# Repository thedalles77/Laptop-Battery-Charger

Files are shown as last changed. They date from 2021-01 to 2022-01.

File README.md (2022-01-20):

# Laptop-Battery-Charger
This repository has all the files that I used to repurpose a Dell D630 laptop into a portable Raspberry Pi. 

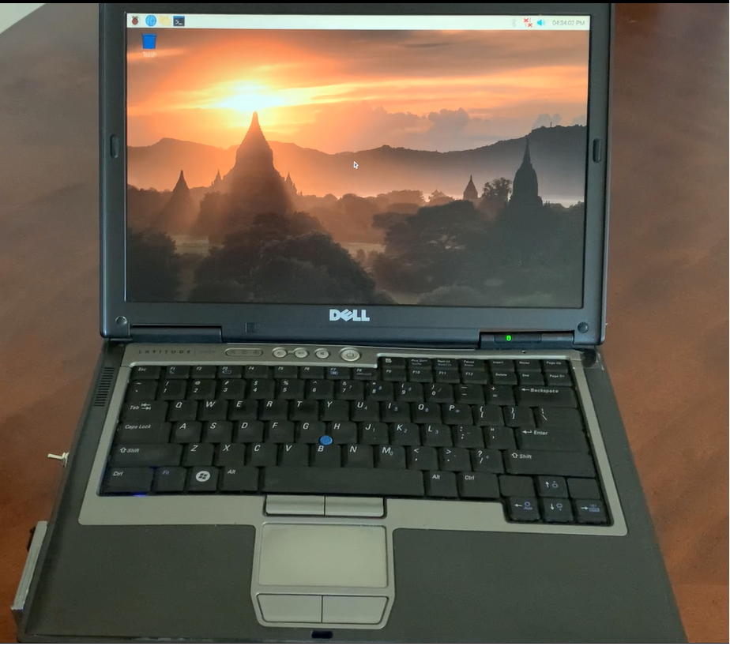
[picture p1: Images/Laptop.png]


The Instructable "Battery Powered Raspberry Pi in Repurposed Laptop" is at this url:

https://www.instructables.com/Battery-Powered-Raspberry-Pi-in-Repurposed-Laptop/

The Video "Portable Raspberry Pi Laptop with a Custom Battery Charger" is at this url:

https://vimeo.com/504006511

The Max1873 based battery charge controller board shown below is detailed as a 
Hackster.IO project at this url:

https://www.hackster.io/frank-adams/laptop-battery-charge-controller-e9c3dc

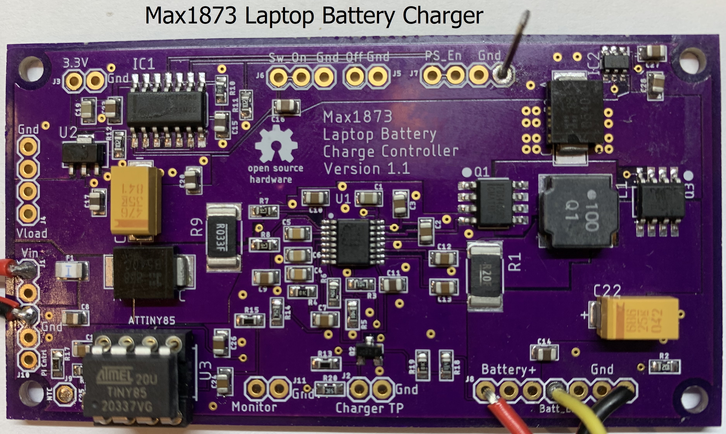
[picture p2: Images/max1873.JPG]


The MP26123 based battery charge controller board shown below is detailed as a 
Hackaday.IO project at this url:

https://hackaday.io/project/177700/details/

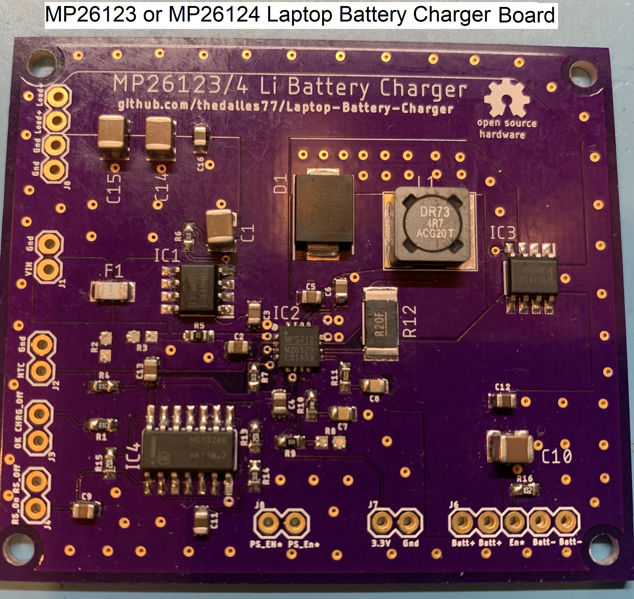
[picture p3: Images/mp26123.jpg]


A battery fuel gauge using Cairo can be found at this location: 
https://github.com/thedalles77/Raspberry-Pi-easy-drawing

The folders at this repo are organized as follows:

  AT Tiny Supervisor folder contains the AT Tiny 85 code to supervise the charging of a 3 series or 4 series wired battery pack.
  
  Eagle_Board_Files folder contains two folders: One for the Max1873 board and one for the MP26123_4 board. They contain the Eagle layout and schematic, parts list, and test procedure.
  
  Dell_D630_Portable_Pi_KVM folder contains the keyboard matrix and Teensy 3.2 Arduino code for controlling the keyboard, touchpad, and video converter card.
  
  My_Ugly_C_Code folder contains the Pi C code that reads the battery status registers over the SMBus.
  
  USB_SMBUS_CP2112 folder contains the Eagle board files to build a USB to SM Bus bridge for reading the battery status registers. See https://github.com/thedalles77/cp2112_demo for the code to display the battery status registers.
  
  Load_Switch_NCP_45760 folder contains the Eagle board files to build a load switch using the On Semiconductor NCP45760 chip.

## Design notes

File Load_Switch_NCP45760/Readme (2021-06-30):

I had problems getting this NCP45760IMN24RTWG load switch to work but I'll provide the information in case someone else has better luck. 
Let me know if you find a way to make it work.
The Eagle board and schematic files are provided along with pictures.
The 3.3 volt regulator can be an AP7381-33V-A through hole or the AP7381-33Y-13 SMD. The caps are 0805 case size and the resistors are 0603 size.
The loads on the switch were two LM2596 buck regulators that provided 10 volts to the video card and 5 volts to the Pi. 
Each buck regulator had a 100uf cap on its input and a 220uf cap on its output with more caps on the Pi and video card.
The input voltage was 19 Volts DC from a wall supply.
I started with the overcurrent resistor R2 set at 10K and the slew rate capacitor C4 set to 0.01uf but this caused the current protection circuit to trip when first enabled.
Changing the R2 resistor to a short did not change anything but changing the C4 slew rate cap to 1uf allowed the switch to work without tripping the protection circuit.
It ran for 30 minutes and the temperature on the chip and input/output traces stabilized at 52 deg C.
Unfortuantely the load switch would not turn off so I apparently ruined the chip by setting the slew rate to a very slow value.
Even changing the slew rate cap to 0.1uf will still exceed the Energy rating based on the formulas in the data sheet.
This leads me to believe that this chip is not usable for my configuration but it may work fine at lower voltages and/or lower currents.

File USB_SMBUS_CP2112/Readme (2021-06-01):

See Step 15 of my Instructable for more information regarding the CP2112:
https://www.instructables.com/Battery-Powered-Raspberry-Pi-in-Repurposed-Laptop/
See the forked version of Nick Dademo's repo for the modified code:
https://github.com/thedalles77/cp2112_demo

The Eagle brd file includes the recommended footprint for the slotted holes on the USB connector.
To fabricate this board at OSH Park, upload the zip file which has been run thru a CAM processor to create the proper slotted holes.

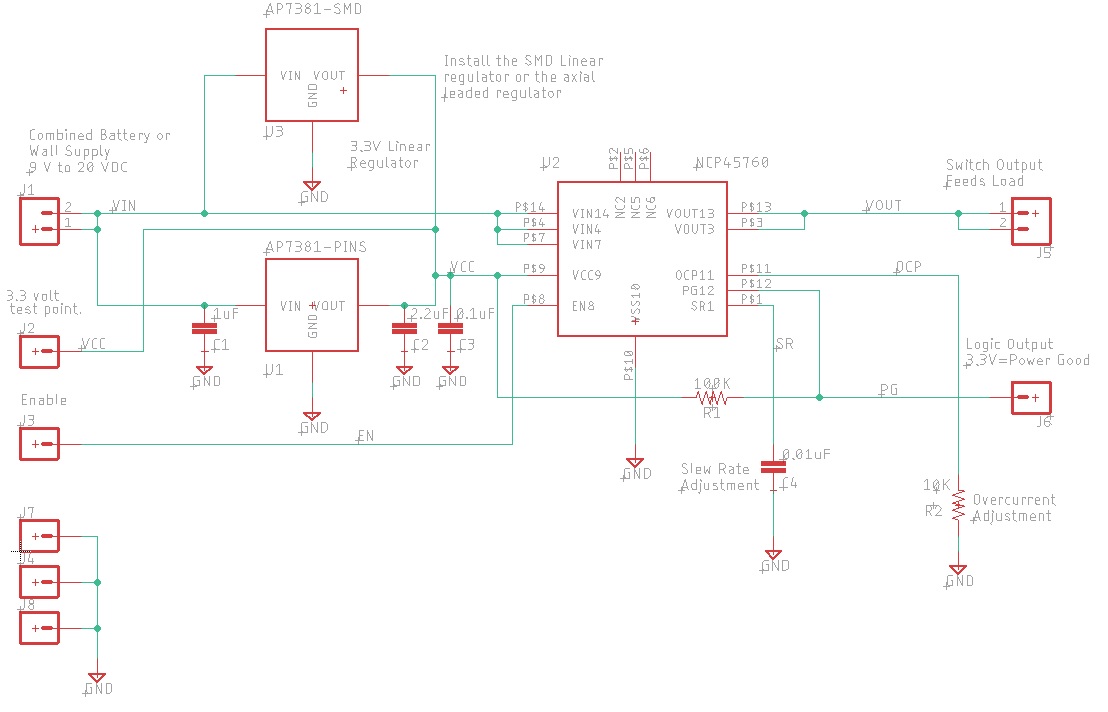
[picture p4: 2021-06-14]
Load_Switch_NCP45760/load_switch_schematic_NCP45760.jpg

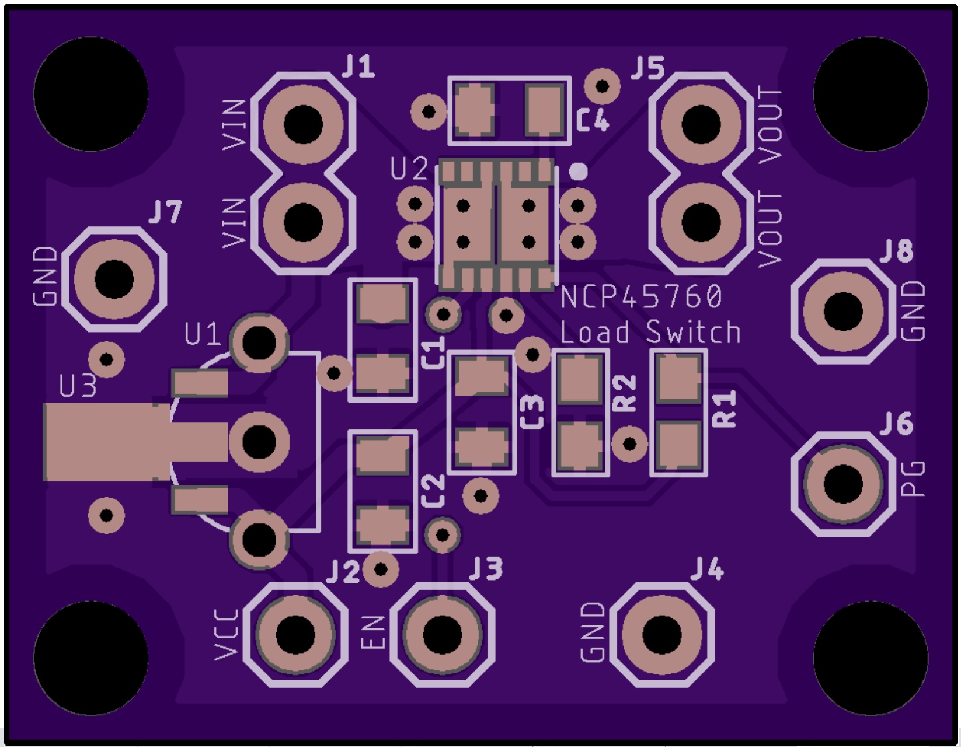
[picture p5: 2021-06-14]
Load_Switch_NCP45760/load_switch_layout_NCP45760.jpg

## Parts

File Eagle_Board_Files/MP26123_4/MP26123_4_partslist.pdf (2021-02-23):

### MP26123 (2S/3S) or MP26124 (4S) Battery Charger Board Parts List

Qty | Description | P/N | Digikey # | Price | Package
1 | Charge Controller 2S/3S MP26123DR-LF-Z 1589-1609-1-ND (https://www.digikey.com/en/products/detail/monolithic-power-systems-inc/MP26123DR-LF-Z/5292163) | $4.92 16-VQFN
Charge Controller 4S | MP26124GR-Z | 1589-1993-1-ND (https://www.digikey.com/en/products/detail/monolithic-power-systems-inc/MP26124GR-Z/8342003) | $4.92 | 16-VQFN
1 | 4.7uH Inductor (2S/3S) | DR73-4R7-R | 513-1133-1-ND (https://www.digikey.com/en/products/detail/eaton-electronics-division/DR73-4R7-R/667201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) | $0.92 | SMD
10uH Inductor (4S) NRS8030T100MJGJ | 587-2960-1-ND (https://www.digikey.com/product-detail/en/taiyo-yuden/NRS8030T100MJGJ/587-2960-1-ND/2666065) | $0.45 | SMD
1 | 3.3 volt regulator | AP7381-33Y-13 | AP7381-33Y-13DICT-ND (https://www.digikey.com/en/products/detail/AP7381-33Y-13/AP7381-33Y-13DIDKR-ND/7914858?itemSeq=322354340) | $0.44 | SOT89
1 | Quad NAND gate | MC74HC132ADTG | MC74HC132ADGOS-ND (https://www.digikey.com/product-detail/en/on-semiconductor/MC74HC132ADG/MC74HC132ADGOS-ND/1479854) $0.37 | 14 pin SOIC
2 | P-FET | FDS4435BZ | FDS4435BZCT-ND (https://www.digikey.com/product-detail/en/on-semiconductor/FDS4435BZ/FDS4435BZCT-ND/1305829) | $0.60 | 8 Pin SOIC
1 | Schottky Diode | B540C | B540C-FDICT-ND (https://www.digikey.com/en/products/detail/diodes-incorporated/B540C-13-F/768771) | $0.48 | DO-214AB
1 | Fuse 5A 32V Slow blow 0469005.WR | F3539CT-ND (https://www.digikey.com/product-detail/en/littelfuse-inc/0469005.WR/F3539CT-ND/2297397) | $0.81 | 1206
5 | 0.1uf 50V X5R Cap | UMK212BJ104KG-T | 587-5486-1-ND (https://www.digikey.com/product-detail/en/taiyo-yuden/UMK212BJ104KG-T/587-5486-1-ND/7067162) | $0.08 | 0805
1 | 0.15uf 50V X5R Cap C2012X7R1H154K085AA 445-14541-1-ND (https://www.digikey.com/en/products/detail/tdk-corporation/C2012X7R1H154K085AA/3951777) | $0.19 | 0805
4 | 1uf 35V Cap | GMK212B7105KG-T | 587-1438-1-ND (https://www.digikey.com/product-detail/en/taiyo-yuden/GMK212B7105KG-T/587-1438-1-ND/1004069) | $0.25 | 0805
1 | 2.2uf 35V Cap | CGA4J1X7R1V225M125AC 445-12769-1-ND (https://www.digikey.com/en/products/detail/tdk-corporation/CGA4J1X7R1V225M125AC/3950005) | $0.51 | 0805
1 | 4.7uf Cap | C1210C475K5RACTU | 399-6785-1-ND (https://www.digikey.com/en/products/detail/kemet/C1210C475K5RACTU/2216923) | $0.60 | 1210
2 | 10uf Cap | GMK325AB7106MM-T | 587-2779-1-ND (https://www.digikey.com/en/products/detail/taiyo-yuden/GMK325AB7106MM-T/2573866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) | $0.69 | 1210
1 | 22uf Cap | C1210C226K3PACTU | 399-11404-1-ND (https://www.digikey.com/en/products/detail/kemet/C1210C226K3PACTU/4747726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) | $0.72 | 1210
2 | 2200pf Cap (2S/3S) CL21B222JBANNNC | 1276-2478-1-ND (https://www.digikey.com/en/products/detail/samsung-electro-mechanics/CL21B222JBANNNC/3888136) | $0.10 | 0805
1 | 2200pf Cap (4S) CL21B222JBANNNC | 1276-2478-1-ND (https://www.digikey.com/en/products/detail/samsung-electro-mechanics/CL21B222JBANNNC/3888136) | $0.10 | 0805

1 4700pf Cap (4S) C0805C472K5RAC7025 C0805C472K5RAC7025CT-ND (https://www.digikey.com/en/products/detail/kemet/C0805C472K5RAC7025/12701326) $0.11 0805

6 | 10KΩ 1% | RNCP0603FTD10K | RNCP0603FTD10K0CT-ND (https://www.digikey.com/product-detail/en/stackpole-electronics-inc/RNCP0603FTD10K0/RNCP0603FTD10K0CT-ND/2240478) | $0.10 | 0603
1 | 10Ω 0.3W | SDR03EZPF10R0 | 511-1693-1-ND (https://www.digikey.com/en/products/detail/rohm-semiconductor/SDR03EZPF10R0/9674943) $0.13 | 0603
3 | 1KΩ 5% | RC0603JR-071KL | 311-1.0KGRCT-ND (https://www.digikey.com/product-detail/en/yageo/RC0603JR-071KL/311-1.0KGRCT-ND/729624) | $0.10 | 0603
1 | 2.49KΩ | RNCP0603FTD2K49 RNCP0603FTD2K49CT-ND (https://www.digikey.com/en/products/detail/stackpole-electronics-inc/RNCP0603FTD2K49/2240117) | $0.10 | 0603
1 | 750Ω | CRCW0603750RFKEAC 541-5551-1-ND (https://www.digikey.com/en/products/detail/vishay-dale/CRCW0603750RFKEAC/7924016) | $0.10 | 0603
1 | 0.2Ω 1% 1W | WSL2512R2000FEA WSLG-.20CT-ND (https://www.digikey.com/product-detail/en/vishay-dale/WSL2512R2000FEA/WSLG-20CT-ND/713508) | $1.05 | 2512

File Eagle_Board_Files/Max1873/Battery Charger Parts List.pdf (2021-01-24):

# Parts List - Laptop Battery Charge Controller

Qty | Description | P/N | Digikey # | Price | Package
1 | Charge Controller 2s MAX1873REEE+ | MAX1873REEE+-ND (https://www.digikey.com/product-detail/en/maxim-integrated/MAX1873REEE/MAX1873REEE-ND/1513342) | $4.26 | 16 Pin QSOP
Charge Controller 3s MAX1873SEEE+ | MAX1873SEEE+-ND (https://www.digikey.com/product-detail/en/MAX1873SEEE%2b/MAX1873SEEE%2b-ND/1513376/?itemSeq=316588766) | $3.78 | 16 Pin QSOP
Charge Controller 4s MAX1873TEEE+ | MAX1873TEEE+-ND (https://www.digikey.com/product-detail/en/maxim-integrated/MAX1873TEEE/MAX1873TEEE-ND/1513377) | $3.78 | 16 Pin QSOP
1 | 3.3 volt regulator | AP7381-33Y-13 | AP7381-33Y-13DICT-ND (https://www.digikey.com/en/products/detail/AP7381-33Y-13/AP7381-33Y-13DIDKR-ND/7914858?itemSeq=322354340) | $0.44 | SOT89
1 | Quad NAND gate | MC74HC132ADTG | MC74HC132ADGOS-ND (https://www.digikey.com/product-detail/en/on-semiconductor/MC74HC132ADG/MC74HC132ADGOS-ND/1479854) $0.37 | 14 pin SOIC
1 | ATTiny85 | ATTINY85-20PU | ATTINY85-20PU-ND (https://www.digikey.com/product-detail/en/microchip-technology/ATTINY85-20PU/ATTINY85-20PU-ND/735469) | $1.20 | 8 Pin DIP
2 | P-FET | FDS4435BZ | FDS4435BZCT-ND (https://www.digikey.com/product-detail/en/on-semiconductor/FDS4435BZ/FDS4435BZCT-ND/1305829) | $0.60 | 8 Pin SOIC
1 | N-FET | MMBF170 | MMBF170CT-ND (https://www.digikey.com/products/en?keywords=mmbf170ct-nd) | $0.37 | SOT-23-3
2 | Schottky Diode | B540C | B540C-FDICT-ND (https://www.digikey.com/en/products/detail/diodes-incorporated/B540C-13-F/768771) | $0.48 | DO-214AB
1 | Ideal Diode Controller LTC4412 LTC4412ES6#TRMPBFCT-ND (https://www.digikey.com/en/products/detail/analog-devices-inc/LTC4412ES6-TRMPBF/1116052) $3.44 | SOT-23-6
1 | Fuse 5A 32V Slow blow 0469005.WR | F3539CT-ND (https://www.digikey.com/product-detail/en/littelfuse-inc/0469005.WR/F3539CT-ND/2297397) | $0.81 | 1206
1 | 10uH, 3A Inductor NRS8030T100MJGJ 587-2960-1-ND (https://www.digikey.com/product-detail/en/taiyo-yuden/NRS8030T100MJGJ/587-2960-1-ND/2666065) | $0.45 | SMD
1 | 68uf, 25V Cap | T495X686K025ATE200 | 399-3908-1-ND (https://www.digikey.com/product-detail/en/T495X686K025ATE200/399-3908-1-ND/819233/?itemSeq=316593616) | $1.96 | 2917
1 | 47uf, 35V Cap | T495X476K035ATE200 399-8543-1-ND (https://www.digikey.com/product-detail/en/T495X476K035ATE200/399-8543-1-ND/3472266/?itemSeq=316593298) | $2.43 | 2917
2 | 2.2uf 10V X5R Cap CC0805MRX5R6BB225 | 311-3438-1-ND (https://www.digikey.com/product-detail/en/yageo/CC0805MRX5R6BB225/311-3438-1-ND/7164459) | $0.18 | 0805
13 | 0.1uf 50V X5R Cap | UMK212BJ104KG-T | 587-5486-1-ND (https://www.digikey.com/product-detail/en/taiyo-yuden/UMK212BJ104KG-T/587-5486-1-ND/7067162) | $0.08 | 0805
2 | 0.22uf 35V Cap | GMK212BJ224KGHT | 587-3366-1-ND (https://www.digikey.com/product-detail/en/taiyo-yuden/GMK212BJ224KGHT/587-3366-1-ND/4157374) | $0.20 | 0805
2 | 0.047uf 50V Cap | 08055C473KAT2A | 478-1391-1-ND (https://www.digikey.com/product-detail/en/avx-corporation/08055C473KAT2A/478-1391-1-ND/564423) | $0.19 | 0805
1 | 1000pf 50V Cap CC0805KRX7R9BB102 | 399-1147-1-ND (https://www.digikey.com/product-detail/en/C0805C102K5RACTU/399-1147-1-ND/411422/?itemSeq=316589801) | $0.14 | 0805
6 | 1uf 35V Cap | GMK212B7105KG-T | 587-1438-1-ND (https://www.digikey.com/product-detail/en/taiyo-yuden/GMK212B7105KG-T/587-1438-1-ND/1004069) | $0.25 | 0805
3 | 100KΩ 0.1% | ERA-3AEB104V | P100KDBCT-ND (https://www.digikey.com/product-detail/en/panasonic-electronic-components/ERA-3AEB104V/P100KDBCT-ND/1466100) | $0.35 | 0603
3 | 10KΩ 1% | RNCP0603FTD10K | RNCP0603FTD10K0CT-ND (https://www.digikey.com/product-detail/en/stackpole-electronics-inc/RNCP0603FTD10K0/RNCP0603FTD10K0CT-ND/2240478) | $0.10 | 0603
3 | 1KΩ 5% | RC0603JR-071KL | 311-1.0KGRCT-ND (https://www.digikey.com/product-detail/en/yageo/RC0603JR-071KL/311-1.0KGRCT-ND/729624) | $0.10 | 0603
2 | 4.7Ω 1% | RNCP0603FTD4R70 RNCP0603FTD4R70CT-ND (https://www.digikey.com/product-detail/en/stackpole-electronics-inc/RNCP0603FTD4R70/RNCP0603FTD4R70CT-ND/2240412) | $0.10 | 0603
1 | 2.49KΩ 0.1% | ERA-3AEB2491V | P2.49KDBCT-ND (https://www.digikey.com/product-detail/en/panasonic-electronic-components/ERA-3AEB2491V/P2.49KDBCT-ND/3075884) | $0.34 | 0603
1 | 7.5KΩ 0.1% | ERA-3AEB752V | P7.5KDBCT-ND (https://www.digikey.com/product-detail/en/panasonic-electronic-components/ERA-3AEB752V/P7.5KDBCT-ND/1466073) | $0.35 | 0603
2 | 49.9KΩ 0.1% | ERA-3AEB4992V | P49.9KDBCT-ND (https://www.digikey.com/product-detail/en/panasonic-electronic-components/ERA-3AEB4992V/P49-9KDBCT-ND/3075986) | $0.34 | 0603
1 | 82KΩ 1% | RC0603FR-0782KL | 311-82.0KHRCT-ND (https://www.digikey.com/en/products/detail/yageo/RC0603FR-0782KL/727400) | $0.10 | 0603
1 | 160KΩ 1% | RC0603FR-07160KL 311-160KHRCT-ND (https://www.digikey.com/en/products/detail/yageo/RC0603FR-07160KL/726973) | $0.10 | 0603
1 | 34.8KΩ 0.5% | RT0603DRE0734K8L 311-2545-1-ND (https://www.digikey.com/en/products/detail/yageo/RT0603DRE0734K8L/1074808) | $0.10 | 0603

1 | 0.033Ω 1% 1W | WSL2512R0330FEA | WSLG-.033CT-ND (https://www.digikey.com/product-detail/en/vishay-dale/WSL2512R0330FEA/WSLG-.033CT-ND/713498) | $1.19 | 2512
1 | 0.2Ω 1% 1W | WSL2512R2000FEA WSLG-.20CT-ND (https://www.digikey.com/product-detail/en/vishay-dale/WSL2512R2000FEA/WSLG-20CT-ND/713508) | $1.05 | 2512
1 | 8 pin Dip socket 110-43-308-41-001000 | ED90032-ND (https://www.digikey.com/product-detail/en/mill-max-manufacturing-corp/110-43-308-41-001000/ED90032-ND/947040) | $0.79 | 8 Pin DIP

### Notes:

Choose the Max1873 R, S, or T version depending on the number of series cells in your battery pack.

Resistors R5 and R6 are each 100KΩ for battery packs that use 3.7 volt nominal/4.2 volt maximum cells. These values must be changed for older battery packs that use 3.6 volt nominal/4.1 volt maximum cells. Using the formulas in the Max1873 data sheet gives new values of: R5 = 54.9KΩ (https://www.digikey.com/en/products/detail/ERA-3AEB5492V/P54.9KDBCT-ND/3076002) and R6 = 147KΩ. (https://www.digikey.com/en/products/detail/ERA-3AEB1473V/P147KDBCT-ND/3075806)

Use the Charge_Controller Eagle layout file to order the PCB from OSH Park. (https://oshpark.com/) The cost with U.S. shipping is $27 for a lot of 3 boards. Use the Charge_Controller Gerber zip file to order the PCB from JLCPCB. The cost with economy U.S. shipping is under $10 for a lot of 5 boards.

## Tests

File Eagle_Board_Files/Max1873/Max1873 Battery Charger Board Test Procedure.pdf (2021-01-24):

Max1873 Battery Charger Board Test Procedure

1. The AT Tiny 85 is not needed during the initial testing and should not be installed.
2. Perform a thorough visual check with a magnifying glass or microscope.
3. Use your ohm meter to verify there are no shorts to ground on any power node.
4. Check that the Max1873 adjacent pins are not shorted together.
5. With the battery disconnected, apply 19 volts DC to the board, preferably with a bench supply so you can dial the current limit down. Verify all voltage nodes with a meter. This should include:
- Vin 19V input
- Battery+ charge voltage. This is dependent on which Max1873 part number is installed (R, S, or T) and resistor values for R5 and R6 (3.6V vs 3.7V cells).
- Vload voltage (confirm the ideal diode circuit is working)
- AT Tiny pin 8 (5.4 Volt regulator from Max1873)
- | The 3.3V pin from the linear regulator powering the | 74HC132A.
6. Verify the digital latch circuit is working. On power up the Ps_En pin should be a logic high (3.3 volts). Momentarily touch the Sw_On pin to ground and verify the Ps_En pin is now a logic low. Momentarily touch the Off pin to 3.3 volts and verify the Ps_En pin is a logic high.
7. Disconnect the 19 volt DC source. Attach the battery to the charger board using a connector. This should tie the "system present" pin of the battery low with a 1K resistor and connect the positive and negative pins of the battery to the charger board. The battery voltage should be present at the Battery+ pin. If not, the battery may be bad or it may need a turn-on activation code over the SMBus. Use the “read_battery_loop.c” code described in the Instructable to see if the battery voltage can now be measured at the Battery+ pin and can be read over the SMBus.
8. Verify the battery voltage is present at the Vload pin – this checks that the "ideal diode" is working.
9. With the battery still connected, connect the 19 volt DC source and measure the battery voltage. Make sure it does not exceed the voltage rating for the battery. Measure the charge current at the Monitor test point. It should be about 1 volt when charging at 1 amp. If the battery voltage is correct but the charging current is near zero, use the “read_battery_loop.c” code described in the Instructable to enable charging. Monitor the battery temperature at all times while charging either by feel or with a temperature probe.
10. Once the battery charger is working properly, disconnect the 19V input and install a programmed AT Tiny 85. Connect 19 volts to the input and confirm normal battery charging operation. You may need to adjust the code in the Tiny for the following:
| • Stop charging when at 100% SOC.
- Stop charging if the temperature rise is too high.
| • Stop charging if the total time is too long.
- Stop charging if the Pi_Control input pin is at 3.3 volts.

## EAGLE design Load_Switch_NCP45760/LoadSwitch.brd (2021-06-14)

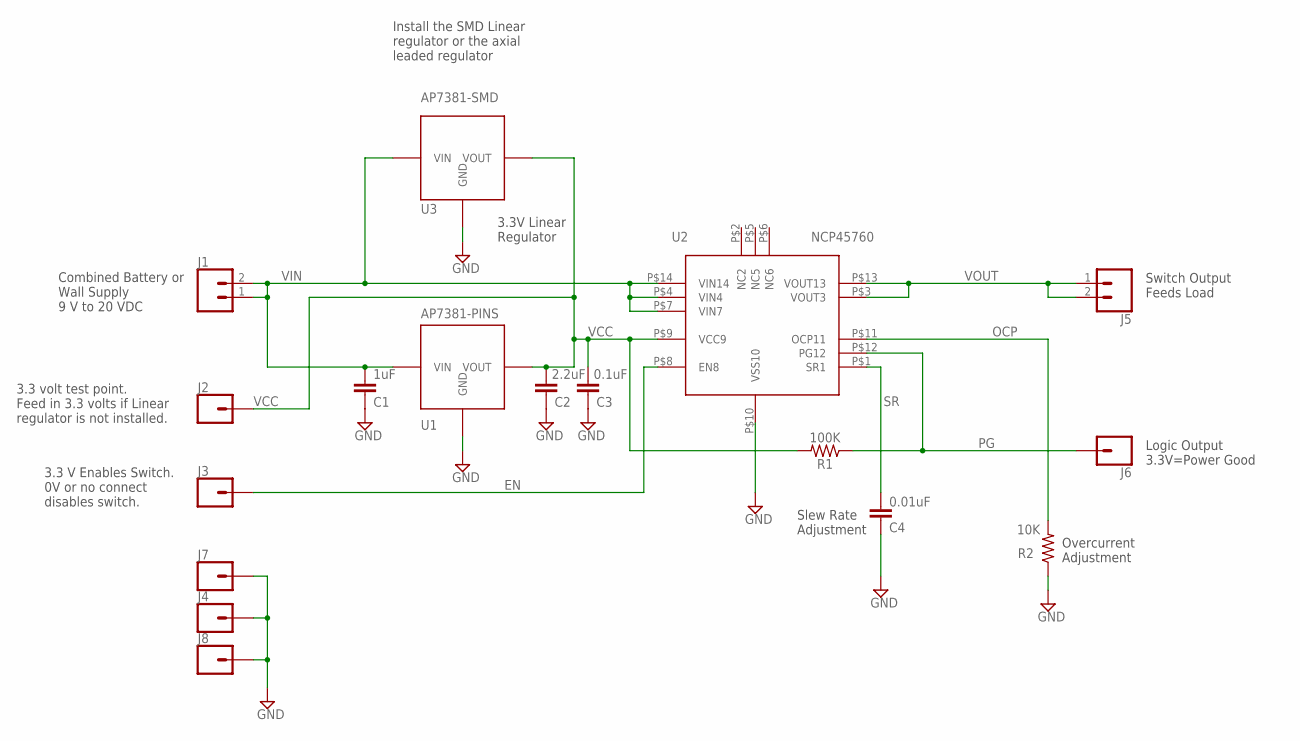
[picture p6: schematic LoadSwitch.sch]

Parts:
C1: 1uF; 0805_CAP
C2: 2.2uF; 0805_CAP
C3: 0.1uF; 0805_CAP
C4: 0.01uF; 0805_CAP
J1, J5: CONN_02; 1X02
J2, J3, J4, J6, J7, J8: CONN_01; 1X01
R1: 100K; 0603_RESISTOR
R2: 10K; 0603_RESISTOR
U1: AP7381-PINS; AP7381_PINS
U2: NCP45760
U3: AP7381-SMD; AP7381

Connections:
EN: J3.1, U2.P$8 (EN8)
GND: C1.2, C2.2, C3.2, C4.2, J4.1, J7.1, J8.1, R2.1, U1.P$2 (GND), U2.P$10 (VSS10), U3.P$3 (GND), U3.P$4 (GND)
OCP: R2.2, U2.P$11 (OCP11)
PG: J6.1, R1.1, U2.P$12 (PG12)
SR: C4.1, U2.P$1 (SR1)
VCC: C2.1, C3.1, J2.1, R1.2, U1.P$1 (VOUT), U2.P$9 (VCC9), U3.P$1 (VOUT)
VIN: C1.1, J1.1, J1.2, U1.P$3 (VIN), U2.P$4 (VIN4), U2.P$7 (VIN7), U2.P$14 (VIN14), U3.P$2 (VIN)
VOUT: J5.1, J5.2, U2.P$3 (VOUT3), U2.P$13 (VOUT13)

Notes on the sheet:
3.3V Linear Regulator
Combined Battery or Wall Supply 9 V to 20 VDC
3.3 volt test point. Feed in 3.3 volts if Linear regulator is not installed.
3.3 V Enables Switch. 0V or no connect disables switch.
Slew Rate Adjustment
Overcurrent Adjustment
Switch Output Feeds Load
Logic Output 3.3V=Power Good
Install the SMD Linear regulator or the axial leaded regulator

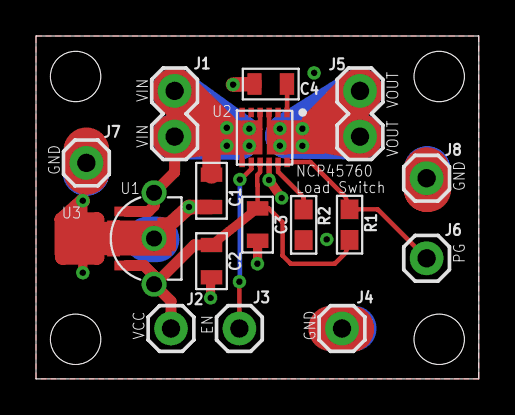
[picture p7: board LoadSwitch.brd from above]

Board: 2 copper layers, 24.6 x 19.1 mm, 18 parts (1 on the bottom side), 8 nets.

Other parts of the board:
U$1: OSHW_5MM

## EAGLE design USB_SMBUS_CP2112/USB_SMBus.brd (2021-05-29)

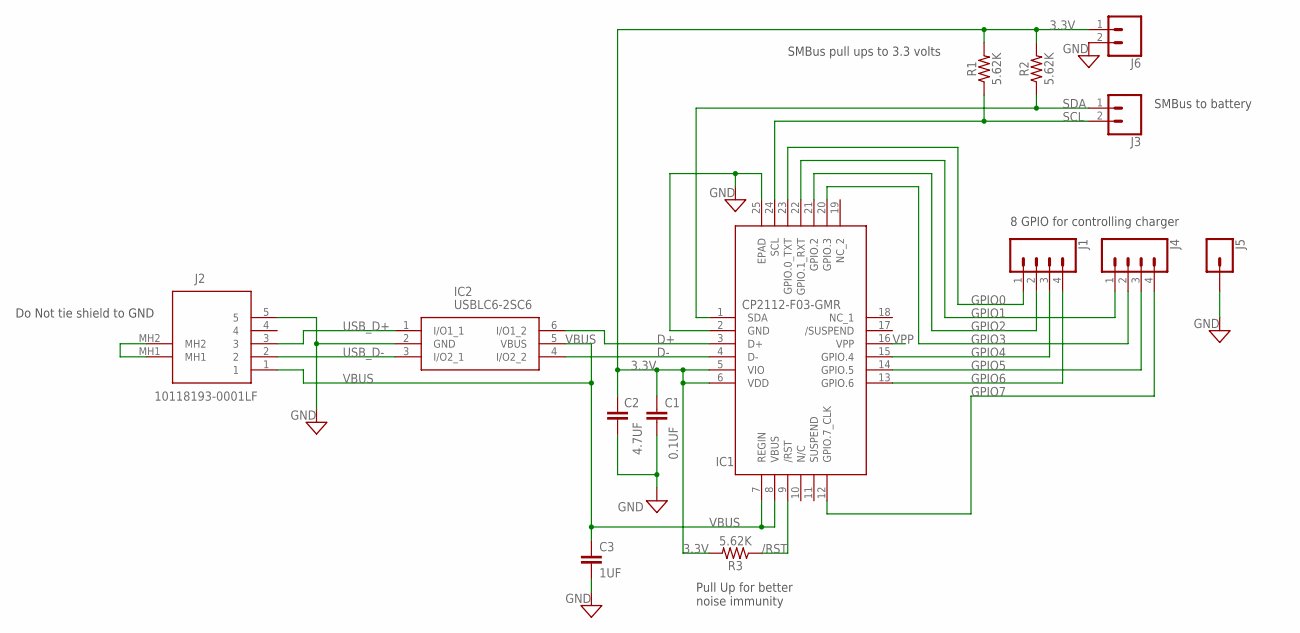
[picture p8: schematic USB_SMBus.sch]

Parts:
C1: 0.1UF; 0805_CAP
C2: 4.7UF; 0805_CAP
C3: 1UF; 0805_CAP
IC1: CP2112-F03-GMR; QFN50P400X400X80-25N
IC2: USBLC6-2SC6; SOT95P280X145-6N
J1, J4: CONN_04; 1X04
J2: 10118193-0001LF; 101181930001LF
J3, J6: CONN_02; 1X02
J5: CONN_01; 1X01
R1, R2, R3: 5.62K; 0603_RESISTOR

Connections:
3.3V: C1.1, C2.1, IC1.5 (VIO), IC1.6 (VDD), J6.1, R1.2, R2.2, R3.2
/RST: IC1.9 (/RST), R3.1
D+: IC1.3 (D+), IC2.6 (I/O1_2)
D-: IC1.4 (D-), IC2.4 (I/O2_2)
GND: C1.2, C2.2, C3.2, IC1.2 (GND), IC1.25 (EPAD), IC2.2 (GND), J2.5, J5.1, J6.2
GPIO0: IC1.23 (GPIO.0_TXT), J1.1
GPIO1: IC1.22 (GPIO.1_RXT), J4.1
GPIO2: IC1.21 (GPIO.2), J1.2
GPIO3: IC1.20 (GPIO.3), J4.2
GPIO4: IC1.15 (GPIO.4), J1.3
GPIO5: IC1.14 (GPIO.5), J4.3
GPIO6: IC1.13 (GPIO.6), J1.4
GPIO7: IC1.12 (GPIO.7_CLK), J4.4
unnamed: J2.MH1, J2.MH2
SCL: IC1.24 (SCL), J3.2, R1.1
SDA: IC1.1 (SDA), J3.1, R2.1
USB_D+: IC2.1 (I/O1_1), J2.3
USB_D-: IC2.3 (I/O2_1), J2.2
VBUS: C3.1, IC1.7 (REGIN), IC1.8 (VBUS), IC2.5 (VBUS), J2.1
VPP: IC1.16 (VPP)

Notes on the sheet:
Pull Up for better noise immunity
Do Not tie shield to GND
SMBus to battery
8 GPIO for controlling charger
SMBus pull ups to 3.3 volts

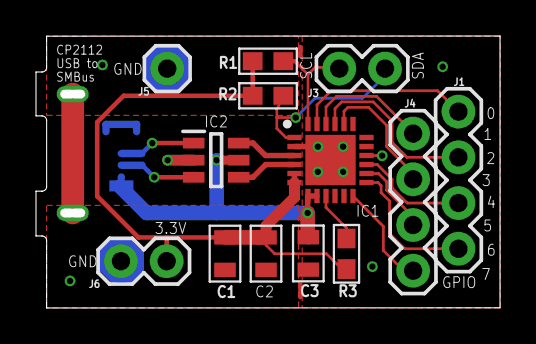
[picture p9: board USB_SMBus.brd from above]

Board: 2 copper layers, 25.8 x 15.1 mm, 14 parts (1 on the bottom side), 19 nets.

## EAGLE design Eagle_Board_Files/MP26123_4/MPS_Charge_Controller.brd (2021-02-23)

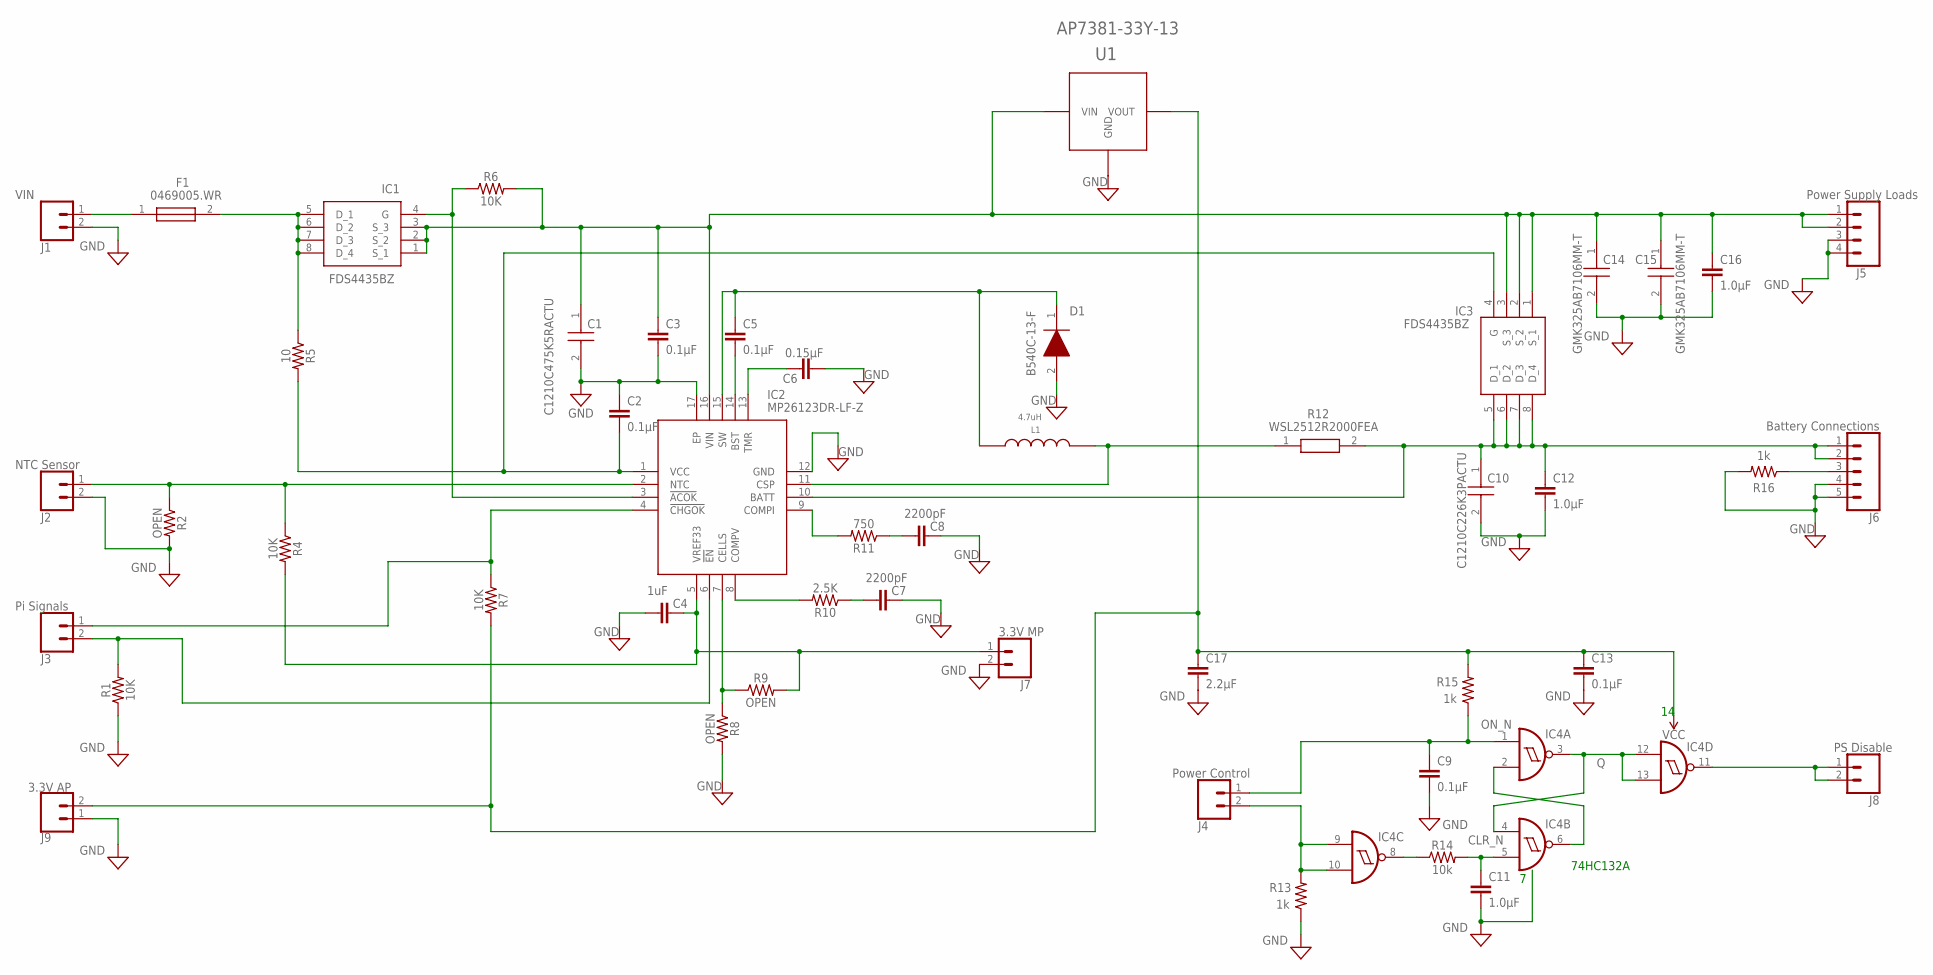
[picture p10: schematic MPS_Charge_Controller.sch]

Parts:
C1: C1210C475K5RACTU; CAPC3225X280N
C2, C3, C5, C9, C13: 0.1µF; 0805
C4: 1uF; 0805
C6: 0.15µF; 0805
C7, C8: 2200pF; 0805
C10: C1210C226K3PACTU; CAPC3225X280N
C11, C12, C16: 1.0µF; 0805
C14, C15: GMK325AB7106MM-T; CAPC3225X270N
C17: 2.2µF; 0805
D1: B540C-13-F; DIOM7959X250N
F1: 0469005.WR; FUSC3216X105N
IC1, IC3: FDS4435BZ; SOIC127P600X175-8N
IC2: MP26123DR-LF-Z; QFN65P400X400X100-17N
IC4: 74132D; SO14
J1: VIN; 1X02
J2: NTC Sensor; 1X02
J3: Pi Signals; 1X02
J4: Power Control; 1X02
J5: Power Supply Loads; 1X04
J6: Battery Connections; 1X05
J7: 3.3V MP; 1X02
J8: PS Disable; 1X02
J9: 3.3V AP; 1X02
L1: 4.7uH; NRS8030
R1, R4, R6, R7: 10K; 0603_RESISTOR
R2, R8, R9: OPEN; 0603_RESISTOR
R5: 10; 0603_RESISTOR
R10: 2.5K; 0603_RESISTOR
R11: 750; 0603_RESISTOR
R12: WSL2512R2000FEA; RESC6332X71N
R13, R15, R16: 1k; 0603
R14: 10k; 0603
U1: AP7381-33Y-13; AP7381

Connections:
BATTERY: C10.1, C12.1, IC2.10 (BATT), IC3.5 (D_1), IC3.6 (D_2), IC3.7 (D_3), IC3.8 (D_4), J6.1, J6.2, R12.2
BST: C5.2, IC2.14 (BST)
CELLS: IC2.7 (CELLS), R8.1, R9.1
CHGOK: IC2.4 (!CHGOK), J3.1, R7.1
CLR_N: C11.1, IC4.5 (I1), R14.2
COMPI: IC2.9 (COMPI), R11.2
COMPV: IC2.8 (COMPV), R10.2
CURRENT_SENSE_P: IC2.11 (CSP), L1.P$2, R12.1
DISABLE: IC2.6 (!EN), J3.2, R1.2
FUSE_OUT: F1.2, IC1.5 (D_1), IC1.6 (D_2), IC1.7 (D_3), IC1.8 (D_4), R5.1
GND: C1.2, C2.1, C3.2, C4.2, C6.2, C7.1, C8.1, C9.2, C10.2, C11.2, C12.2, C13.2, C14.2, C15.2, C16.2, C17.2, D1.2 (A), IC2.12 (GND), IC2.17 (EP), IC4.7 (GND), J1.2, J2.2, J5.3, J5.4, J6.4, J6.5, J7.2, J9.1, R1.1, R2.2, R8.2, R13.1, R16.2, U1.P$3 (GND), U1.P$4 (GND)
INPUT_GATE: IC1.4 (G), IC2.3 (!ACOK), R6.1
INTERNAL_SW: C5.1, D1.1 (K), IC2.15 (SW), L1.P$1
MP3V3: C4.1, IC2.5 (VREF33), J7.1, R4.2, R9.2
unnamed: C8.2, R11.1
unnamed: C7.2, R10.1
unnamed: F1.1, J1.1
NTC: IC2.2 (NTC), J2.1, R2.1, R4.1
ON_N: C9.1, IC4.1 (I0), J4.1, R15.1
PS_DISABLE: IC4.11 (O), J8.1, J8.2
Q: IC4.3 (O), IC4.4 (I0), IC4.12 (I0), IC4.13 (I1)
QBAR: IC4.2 (I1), IC4.6 (O)
SYSTEM_PRESENT: J6.3, R16.1
TMR: C6.1, IC2.13 (TMR)
TURN_OFF: IC4.9 (I0), IC4.10 (I1), J4.2, R13.2
TURN_OFF_N: IC4.8 (O), R14.1
V3P3: C13.1, C17.1, IC4.14 (VCC), J9.2, R7.2, R15.2, U1.P$1 (VOUT)
VCC: C2.2, IC2.1 (VCC), IC3.4 (G), R5.2
VLOAD: C1.1, C3.1, C14.1, C15.1, C16.1, IC1.1 (S_1), IC1.2 (S_2), IC1.3 (S_3), IC2.16 (VIN), IC3.1 (S_1), IC3.2 (S_2), IC3.3 (S_3), J5.1, J5.2, R6.2, U1.P$2 (VIN)

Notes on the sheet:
74HC132A

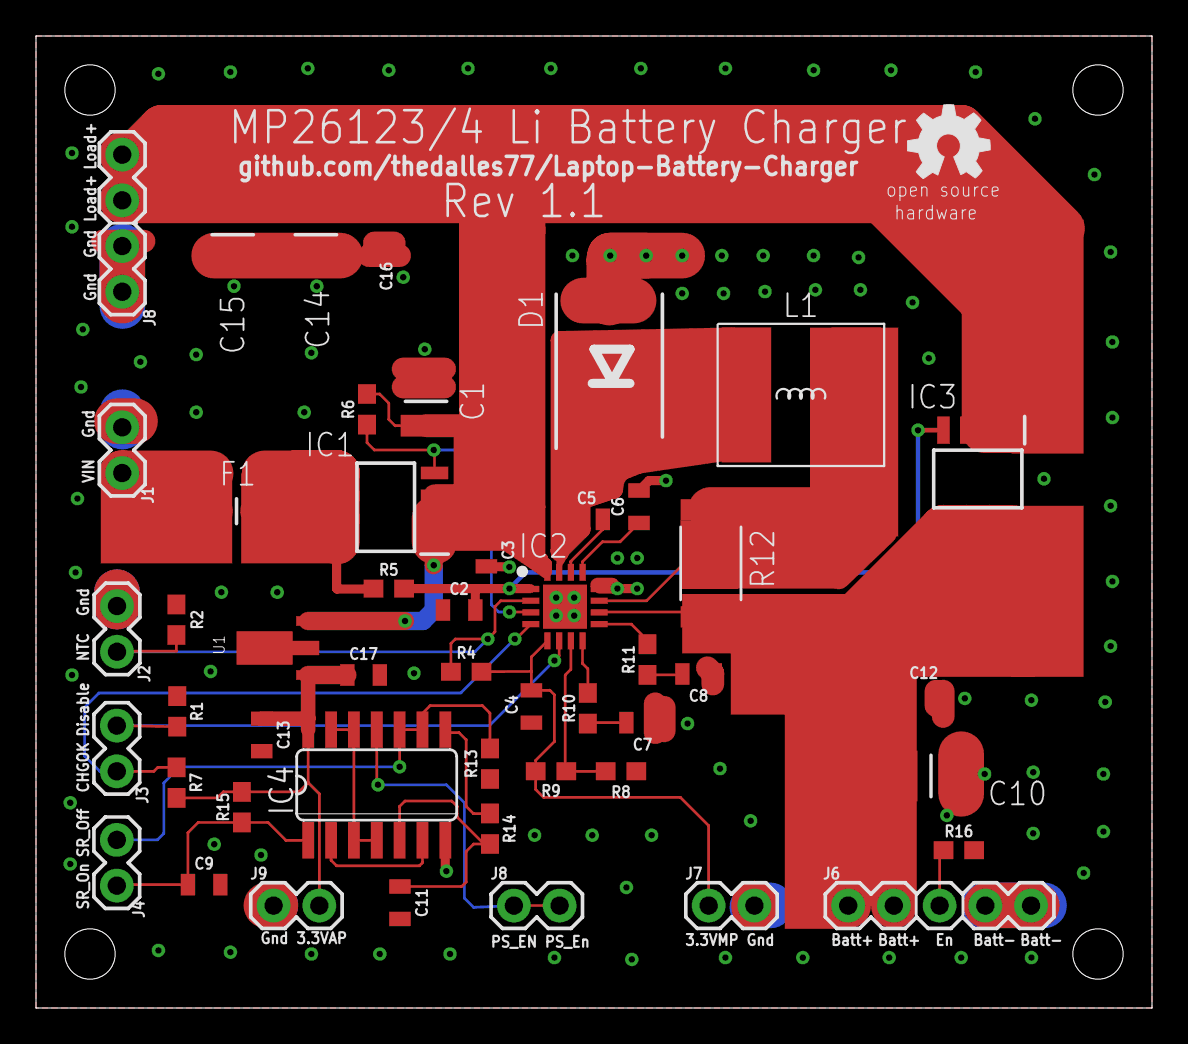
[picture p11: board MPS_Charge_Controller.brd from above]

Board: 2 copper layers, 62.0 x 54.0 mm, 50 parts (0 on the bottom side), 29 nets.

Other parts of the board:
U$1: OSHW_5MM

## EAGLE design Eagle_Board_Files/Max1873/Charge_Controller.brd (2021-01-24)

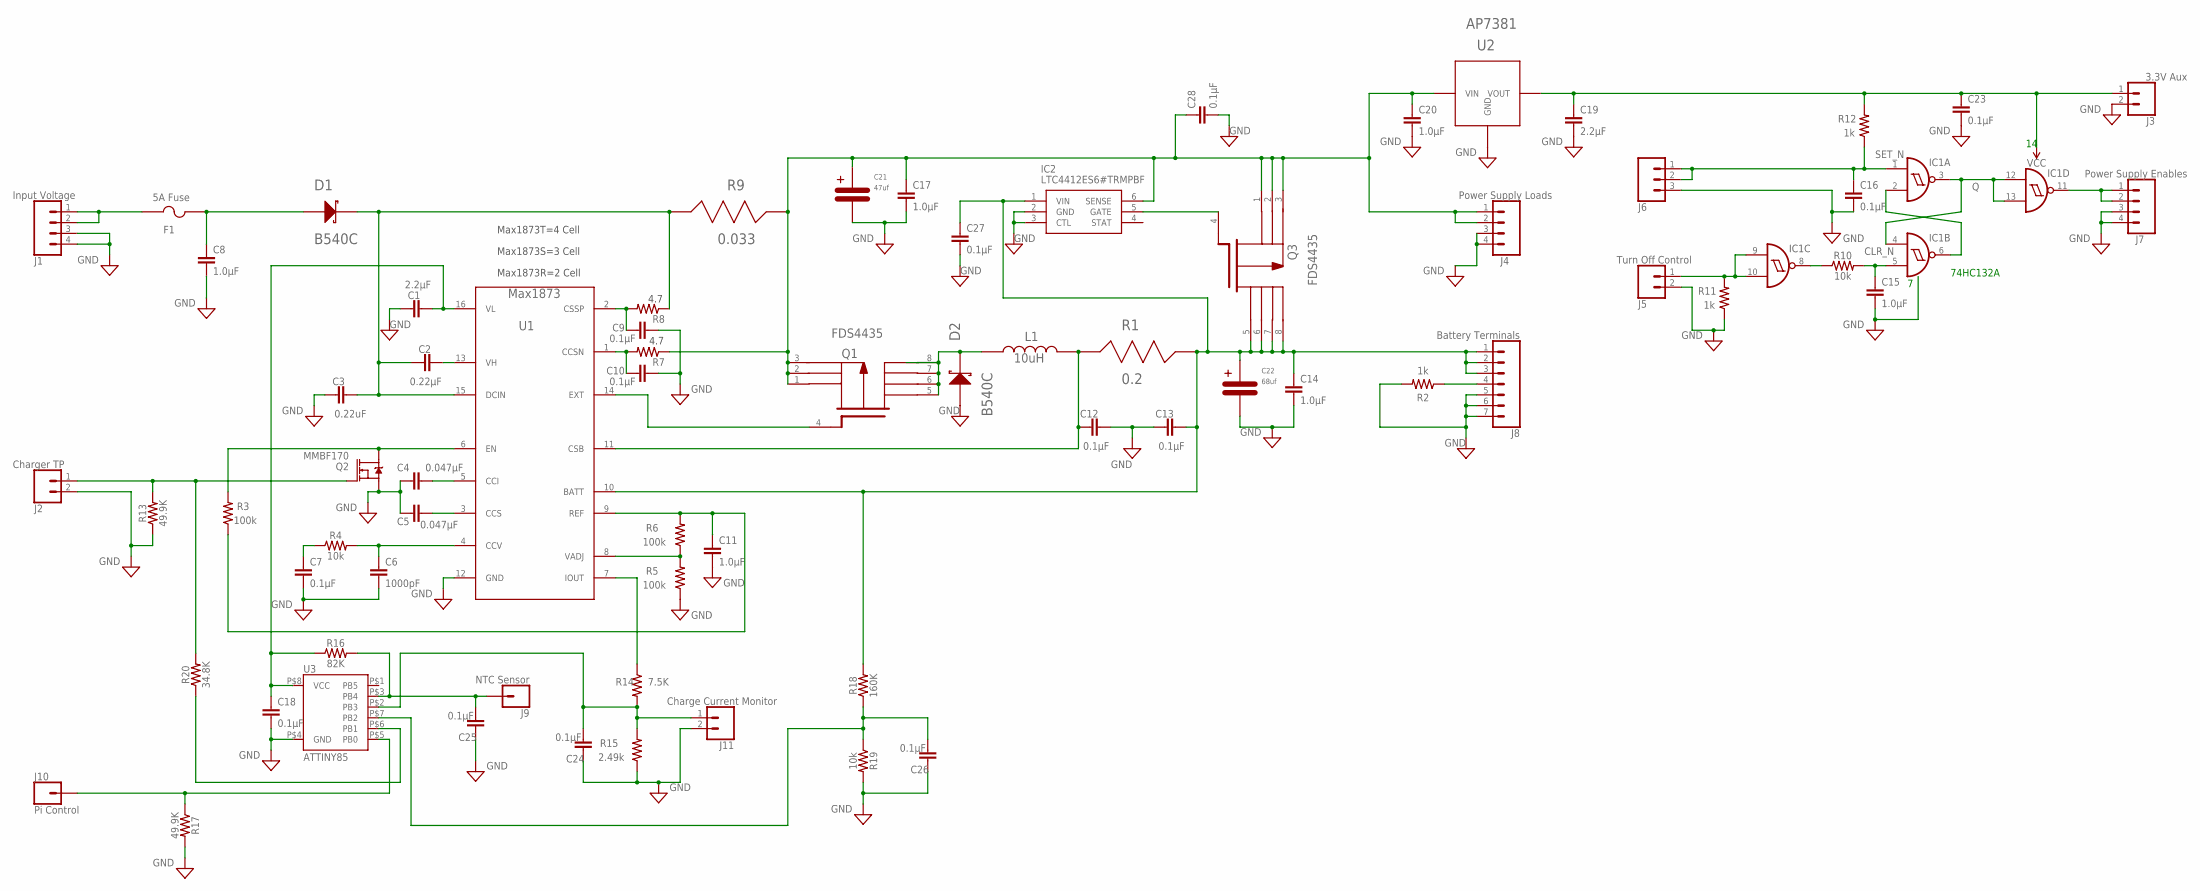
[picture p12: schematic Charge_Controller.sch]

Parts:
C1, C19: 2.2µF; 0805
C2: 0.22µF; 0805
C3: 0.22uF; 0805
C4, C5: 0.047µF; 0805
C6: 1000pF; 0805
C7, C9, C10, C12, C13, C16, C18, C23, C24, C25, C26, C27, C28: 0.1µF; 0805
C8, C11, C14, C15, C17, C20: 1.0µF; 0805
C21: 47uf; 2917
C22: 68uf; 2917
D1, D2: B540C
F1: 5A Fuse; FUSE1206
IC1: 74132D; SO14
IC2: LTC4412ES6#TRMPBF; SOT95P280X100-6N
J1: Input Voltage; 1X04
J2: Charger TP; 1X02
J3: 3.3V Aux; 1X02
J4: Power Supply Loads; 1X04
J5: Turn Off Control; 1X02
J6: Turn On; 1X03
J7: Power Supply Enables; 1X04
J8: Battery Terminals; 1X07
J9: NTC Sensor; 1X01
J10: Pi Control; 1X01
J11: Charge Current Monitor; 1X02
L1: 10uH; NRS8030
Q1, Q3: FDS4435
Q2: MMBF170
R1: 0.2; 2512
R2, R11, R12: 1k; 0603
R3, R5, R6: 100k; 0603
R4, R10, R19: 10k; 0603
R7, R8: 4.7; 0603_4P7
R9: 0.033; 2512
R13: 49.9K; 0603_RESISTOR
R14: 7.5K; 0603_RESISTOR
R15: 2.49k; 0603
R16: 82K; 0603_RESISTOR
R17: 49.9K; 0603
R18: 160K; 0603_RESISTOR
R20: 34.8K; 0603_RESISTOR
U1: Max1873; MAX1873
U2: AP7381
U3: ATTINY85

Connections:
BATT: C13.2, C14.1, C22.POS, C27.1, IC2.1 (VIN), J8.1, J8.2, J8.3, Q3.5 (D5), Q3.6 (D6), Q3.7 (D7), Q3.8 (D8), R1.P$2, R18.2, U1.10 (BATT)
BATT_ENABLE: J8.4, R2.1
BATT_ISENSE: C12.1, L1.P$2, R1.P$1, U1.11 (CSB)
CCI: C4.2, U1.5 (CCI)
CCS: C5.2, U1.3 (CCS)
CCSN: C10.1, R7.2, U1.1 (CCSN)
CCV: C6.1, R4.2, U1.4 (CCV)
CCV_MID: C7.1, R4.1
CHARGE_DISABLE: R20.1, U3.P$6 (PB1)
CHARGE_MONITOR: C24.2, J11.1, R14.2, R15.2, U3.P$2 (PB3)
CLR_N: C15.1, IC1.5 (I1), R10.2
CSSP: C9.1, R8.2, U1.2 (CSSP)
DIODE_GATE: IC2.5 (GATE), Q3.4 (G4)
DISABLE_GATE: J2.1, Q2.1 (G), R13.2, R20.2
EN: Q2.3 (D), R3.2, U1.6 (EN)
FET_D: D2.P$2, L1.P$1, Q1.5 (D5), Q1.6 (D6), Q1.7 (D7), Q1.8 (D8)
FET_G: Q1.4 (G4), U1.14 (EXT)
GND: C1.1, C3.1, C4.1, C5.1, C6.2, C7.2, C8.2, C9.2, C10.2, C11.2, C12.2, C13.1, C14.2, C15.2, C16.2, C17.2, C18.2, C19.2, C20.2, C21.NEG, C22.NEG, C23.2, C24.1, C25.1, C26.1, C27.2, C28.2, D2.P$1, IC1.7 (GND), IC2.2 (GND), IC2.3 (CTL), J1.3, J1.4, J2.2, J3.2, J4.3, J4.4, J5.2, J6.3, J7.3, J7.4, J8.5, J8.6, J8.7, J11.2, Q2.2 (S), R2.2, R5.1, R11.1, R13.1, R15.1, R17.2, R19.2, U1.12 (GND), U2.P$3 (GND), U2.P$4 (GND), U3.P$4 (GND)
INPUT_V: F1.P$1, J1.1, J1.2
unnamed: R14.1, U1.7 (IOUT)
NTC: C25.2, J9.1, R16.2, U3.P$3 (PB4)
PI_CONTROL: J10.1, R17.1, U3.P$5 (PB0)
PS_EN: IC1.11 (O), J7.1, J7.2
Q: IC1.3 (O), IC1.4 (I0), IC1.12 (I0), IC1.13 (I1)
QBAR: IC1.2 (I1), IC1.6 (O)
REF: C11.1, R3.1, R6.2, U1.9 (REF)
SET_N: C16.1, IC1.1 (I0), J6.1, J6.2, R12.1
TURN_OFF: IC1.9 (I0), IC1.10 (I1), J5.1, R11.2
TURN_OFF_N: IC1.8 (O), R10.1
VADJ: R5.2, R6.1, U1.8 (VADJ)
VBAT_DIV: C26.2, R18.1, R19.1, U3.P$7 (PB2)
VCC: C19.1, C23.1, IC1.14 (VCC), J3.1, R12.2, U2.P$1 (VOUT)
VH: C2.2, U1.13 (VH)
VIN_DIODE: C2.1, C3.2, D1.P$2, R8.1, R9.P$2, U1.15 (DCIN)
VIN_FUSE: C8.1, D1.P$1, F1.P$2
VL: C1.2, C18.1, R16.1, U1.16 (VL), U3.P$8 (VCC)
VLOAD: C17.1, C20.1, C21.POS, C28.1, IC2.6 (SENSE), J4.1, J4.2, Q1.1 (S1), Q1.2 (S2), Q1.3 (S3), Q3.1 (S1), Q3.2 (S2), Q3.3 (S3), R7.1, R9.P$1, U2.P$2 (VIN)

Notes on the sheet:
74HC132A
4.7
Max1873T=4 Cell
Max1873S=3 Cell
Max1873R=2 Cell

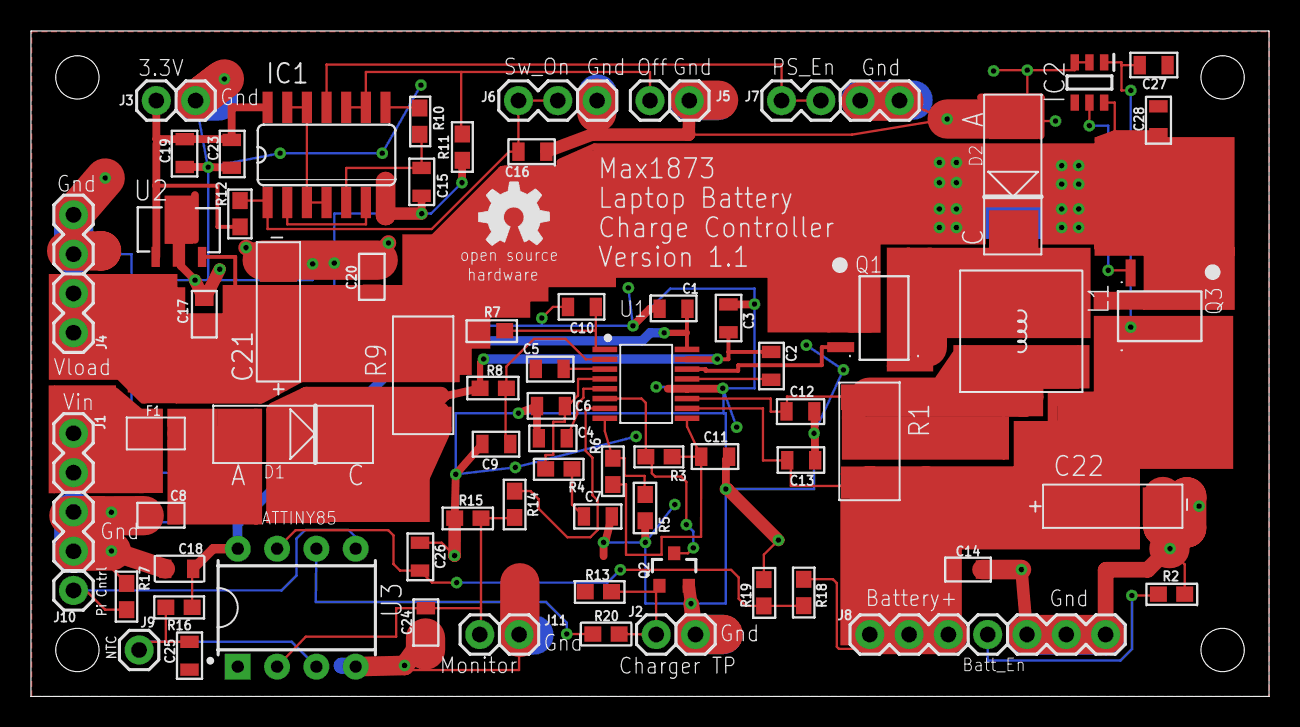
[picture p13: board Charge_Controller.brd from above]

Board: 2 copper layers, 80.0 x 43.0 mm, 72 parts (0 on the bottom side), 37 nets.

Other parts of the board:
U$1: OSHW_5MM

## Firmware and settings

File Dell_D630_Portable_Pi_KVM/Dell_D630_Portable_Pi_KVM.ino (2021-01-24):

/* Copyright 2019 Frank Adams
   Licensed under the Apache License, Version 2.0 (the "License");
   you may not use this file except in compliance with the License.
   You may obtain a copy of the License at
       http://www.apache.org/licenses/LICENSE-2.0
   Unless required by applicable law or agreed to in writing, software
   distributed under the License is distributed on an "AS IS" BASIS,
   WITHOUT WARRANTIES OR CONDITIONS OF ANY KIND, either express or implied.
   See the License for the specific language governing permissions and
   limitations under the License.
*/
// This software implements a Dell Latitude D630 Laptop Keyboard Controller and PS/2 Touchpad Controller
// using a Teensy 3.2 on a daughterboard with a 34 pin FPC connector. The keyboard part number 
// is DP/N 0DR160. The Touchpad is from a Dell D630. The touchpad chip part number is 3JA1CA024B.
// This routine uses the Teensyduino "Micro-Manager Method" to send Normal and Modifier 
// keys over USB. Multi-media keys are sent with keyboard press and release functions.
// Description of Teensyduino keyboard functions is at www.pjrc.com/teensy/td_keyboard.html
// The PS/2 code has a watchdog timer so the code doesn't hang if the Teensy is interrupted by USB traffic.
//
// In the Arduino IDE, select Tools, Teensy 3.2. Also under Tools, select Keyboard+Mouse+Joystick
//
// Revision History
// Rev 1.0 - Nov 3, 2020 - Original Release
//
#define MODIFIERKEY_FN 0x8f   // give Fn key a HID code 
#define CAPS_LED 30 // Caps lock LED on keyboard shows bit 1 in keyboard_led variable
//                 #define SCRL_LED 29 // Scroll lock LED on keyboard shows bit 2 in keyboard_leds variable
#define NUM_LED 31 // Num lock LED on keyboard shows bit 0 in keyboard_leds variable 
//
#define TP_DATA 14 // Touchpad ps/2 data connected to Teensy I/O pin 14
#define TP_CLK 23  // Touchpad ps/2 clock connected to Teensy I/O pin 23
//
#define VIDEO_MENU 15 // Video converter card - Menu signal on pad K4 
#define VIDEO_RIGHT 32 // Video converter card - Right signal on pad K1
//
#define TURN_OFF 13 // Teensy drives this output high to disable power supplies
#define PI_CONTROL 29 // Pi drives this logic signal low when it wants to shut down
//
const byte rows_max = 18; // sets the number of rows in the matrix
const byte cols_max = 8; // sets the number of columns in the matrix
//
// Load the normal key matrix with the Teensyduino key names described at www.pjrc.com/teensy/td_keyboard.html
// A zero indicates no normal key at that location.
//
int normal[rows_max][cols_max] = {
  {0,KEY_INSERT,0,KEY_F12,0,0,0,KEY_RIGHT},
  {0,KEY_DELETE,0,KEY_F11,0,0,0,KEY_DOWN},
  {KEY_UP,KEY_HOME,KEY_MENU,KEY_END,0,0,KEY_PAUSE,KEY_LEFT},
  {0,KEY_F8,KEY_F7,KEY_9,KEY_O,KEY_L,KEY_PERIOD,0},
  {KEY_QUOTE,KEY_MINUS,KEY_LEFT_BRACE,KEY_0,KEY_P,KEY_SEMICOLON,0,KEY_SLASH},
  {KEY_F6,KEY_EQUAL,KEY_RIGHT_BRACE,KEY_8,KEY_I,KEY_K,KEY_COMMA,0},
  {KEY_H,KEY_6,KEY_Y,KEY_7,KEY_U,KEY_J,KEY_M,KEY_N},
  {KEY_F5,KEY_F9,KEY_BACKSPACE,KEY_F10,0,KEY_BACKSLASH,KEY_ENTER,KEY_SPACE},
  {KEY_G,KEY_5,KEY_T,KEY_4,KEY_R,KEY_F,KEY_V,KEY_B},
  {KEY_F4,KEY_F2,KEY_F3,KEY_3,KEY_E,KEY_D,KEY_C,0},
  {0,KEY_F1,KEY_CAPS_LOCK,KEY_2,KEY_W,KEY_S,KEY_X,0},
  {KEY_ESC,KEY_TILDE,KEY_TAB,KEY_1,KEY_Q,KEY_A,KEY_Z,0},
  {0,0,0,KEY_PRINTSCREEN,KEY_NUM_LOCK,0,0,0},
  {0,0,0,0,0,0,0,0},
  {0,0,0,0,0,0,0,0},
  {0,0,0,0,KEY_PAGE_UP,KEY_PAGE_DOWN,0,0},
  {0,0,0,0,0,0,0,0},
  {0,0,0,0,0,0,0,0}
};
// Load the modifier key matrix with key names at the correct row-column location. 
// A zero indicates no modifier key at that location.
int modifier[rows_max][cols_max] = {
  {0,0,0,0,0,0,0,0},
  {0,0,0,0,0,0,0,0},
  {0,0,0,0,0,0,0,0},
  {0,0,0,0,0,0,0,0},
  {0,0,0,0,0,0,0,0},
  {0,0,0,0,0,0,0,0},
  {0,0,0,0,0,0,0,0},
  {0,0,0,0,0,0,0,0},
  {0,0,0,0,0,0,0,0},   
  {0,0,0,0,0,0,0,0},
  {0,0,0,0,0,0,0,0},
  {0,0,0,0,0,0,0,0},
  {MODIFIERKEY_LEFT_ALT,0,0,0,0,0,0,MODIFIERKEY_RIGHT_ALT},    
  {0,0,MODIFIERKEY_LEFT_SHIFT,0,0,0,MODIFIERKEY_RIGHT_SHIFT,0},
  {0,MODIFIERKEY_LEFT_CTRL,0,0,0,0,MODIFIERKEY_RIGHT_CTRL,0},
  {0,0,0,MODIFIERKEY_GUI,0,0,0,0},
  {0,0,0,0,0,MODIFIERKEY_FN,0,0},
  {0,0,0,0,0,0,0,0}  
};
// Load the media key matrix with Fn key names at the correct row-column location. 
// Notice the volume controls need the Fn key pressed.
// A zero indicates no media key at that location.
int media[rows_max][cols_max] = {
  {0,0,0,0,0,0,0,0},
  {0,0,0,0,0,0,0,0},
  {0,0,0,0,0,0,0,0},
  {0,0,0,0,0,0,0,0},
  {0,0,0,0,0,0,0,0},
  {0,0,0,0,0,0,0,0},
  {0,0,0,0,0,0,0,0},   
  {0,0,0,0,0,0,0,0},
  {0,0,0,0,0,0,0,0},
  {0,0,0,0,0,0,0,0},
  {0,KEY_SYSTEM_SLEEP,0,0,0,0,0,0},   
  {0,0,0,0,0,0,0,0},
  {0,0,0,0,KEY_SCROLL_LOCK,0,0,0},
  {0,0,0,0,0,0,0,0},
  {0,0,0,0,0,0,0,0},
  {0,0,0,0,0,0,0,0},
  {0,0,0,0,0,0,0,0},
  {0,0,0,KEY_MEDIA_VOLUME_DEC,0,KEY_MEDIA_VOLUME_INC,KEY_MEDIA_MUTE,0}
};
// Initialize the old_key matrix with one's. 
// 1 = key not pressed, 0 = key is pressed
boolean old_key[rows_max][cols_max] = {
  {1,1,1,1,1,1,1,1},
  {1,1,1,1,1,1,1,1},
  {1,1,1,1,1,1,1,1},
  {1,1,1,1,1,1,1,1},
  {1,1,1,1,1,1,1,1},
  {1,1,1,1,1,1,1,1},
  {1,1,1,1,1,1,1,1},
  {1,1,1,1,1,1,1,1},
  {1,1,1,1,1,1,1,1},
  {1,1,1,1,1,1,1,1},
  {1,1,1,1,1,1,1,1},
  {1,1,1,1,1,1,1,1},
  {1,1,1,1,1,1,1,1},
  {1,1,1,1,1,1,1,1},
  {1,1,1,1,1,1,1,1},  
  {1,1,1,1,1,1,1,1},
  {1,1,1,1,1,1,1,1},
  {1,1,1,1,1,1,1,1}
};
//
// Define the Teensy 3.2 I/O numbers (translated from the FPC pin #)
// Row FPC pin # 02,03,04,05,06,07,08,09,10,11,12,13,14,15,16,17,18,31
// Teensy I/O  # 00,22,01,21,02,20,03,19,04,18,05,17,06,24,07,25,08,16
int Row_IO[rows_max] = {0,22,1,21,2,20,3,19,4,18,5,17,6,24,7,25,8,16}; // Teensy 3.2 I/O numbers for rows
//
// Column FPC pin # 19,20,21,22,23,24,25,26
// Teensy I/O     # 33,09,26,10,27,11,28,12
int Col_IO[cols_max] = {33,9,26,10,27,11,28,12};  // Teensy 3.2 I/O numbers for columns

// Declare variables that will be used by functions
boolean touchpad_error = LOW; // set high if the touchpad failes to give the correct response
boolean slots_full = LOW; // Goes high when slots 1 thru 6 contain normal keys
// slot 1 thru slot 6 hold the normal key values to be sent over USB. 
int slot1 = 0; //value of 0 means the slot is empty and can be used.  
int slot2 = 0; 
int slot3 = 0; 
int slot4 = 0; 
int slot5 = 0; 
int slot6 = 0;
//
int mod_shift_l = 0; // These variables are sent over USB as modifier keys.
int mod_shift_r = 0; // Each is either set to 0 or MODIFIER_ ... 
int mod_ctrl_l = 0;   
int mod_ctrl_r = 0;
int mod_alt_l = 0;
int mod_alt_r = 0;
int mod_gui = 0;
//
// Function to load the key name into the first available slot
void load_slot(int key) {
  if (!slot1)  {
    slot1 = key;
  }
  else if (!slot2) {
    slot2 = key;
  }
  else if (!slot3) {
    slot3 = key;
  }
  else if (!slot4) {
    slot4 = key;
  }
  else if (!slot5) {
    slot5 = key;
  }
  else if (!slot6) {
    slot6 = key;
  }
  if (!slot1 || !slot2 || !slot3 || !slot4 || !slot5 || !slot6)  {
    slots_full = LOW; // slots are not full
  }
  else {
    slots_full = HIGH; // slots are full
  } 
}
//
// Function to clear the slot that contains the key name
void clear_slot(int key) {
  if (slot1 == key) {
    slot1 = 0;
  }
  else if (slot2 == key) {
    slot2 = 0;
  }
  else if (slot3 == key) {
    slot3 = 0;
  }
  else if (slot4 == key) {
    slot4 = 0;
  }
  else if (slot5 == key) {
    slot5 = 0;
  }
  else if (slot6 == key) {
    slot6 = 0;
  }
  if (!slot1 || !slot2 || !slot3 || !slot4 || !slot5 || !slot6)  {
    slots_full = LOW; // slots are not full
  }
  else {
    slots_full = HIGH; // slots are full
  } 
}
//
// Function to load the modifier key name into the appropriate mod variable
void load_mod(int m_key) {
  if (m_key == MODIFIERKEY_LEFT_SHIFT)  {
    mod_shift_l = m_key;
  }
  else if (m_key == MODIFIERKEY_RIGHT_SHIFT)  {
    mod_shift_r = m_key;
  }
  else if (m_key == MODIFIERKEY_LEFT_CTRL)  {
    mod_ctrl_l = m_key;
  }
  else if (m_key == MODIFIERKEY_RIGHT_CTRL)  {
    mod_ctrl_r = m_key;
  }
  else if (m_key == MODIFIERKEY_LEFT_ALT)  {
    mod_alt_l = m_key;
  }
  else if (m_key == MODIFIERKEY_RIGHT_ALT)  {
    mod_alt_r = m_key;
  }
  else if (m_key == MODIFIERKEY_GUI)  {
    mod_gui = m_key;
  }
}
//
// Function to load 0 into the appropriate mod variable
void clear_mod(int m_key) {
  if (m_key == MODIFIERKEY_LEFT_SHIFT)  {
    mod_shift_l = 0;
  }
  else if (m_key == MODIFIERKEY_RIGHT_SHIFT)  {
    mod_shift_r = 0;
  }
  else if (m_key == MODIFIERKEY_LEFT_CTRL)  {
    mod_ctrl_l = 0;
  }
  else if (m_key == MODIFIERKEY_RIGHT_CTRL)  {
    mod_ctrl_r = 0;
  }
  else if (m_key == MODIFIERKEY_LEFT_ALT)  {
    mod_alt_l = 0;
  }
  else if (m_key == MODIFIERKEY_RIGHT_ALT)  {
    mod_alt_r = 0;
  }
  else if (m_key == MODIFIERKEY_GUI)  {
    mod_gui = 0;
  }
}
//
// Function to send the modifier keys over usb
void send_mod() {
  Keyboard.set_modifier(mod_shift_l | mod_shift_r | mod_ctrl_l | mod_ctrl_r | mod_alt_l | mod_alt_r | mod_gui);
  Keyboard.send_now();
}
//
// Function to send the normal keys in the 6 slots over usb
void send_normals() {
  Keyboard.set_key1(slot1);
  Keyboard.set_key2(slot2);
  Keyboard.set_key3(slot3);
  Keyboard.set_key4(slot4);
  Keyboard.set_key5(slot5);
  Keyboard.set_key6(slot6);
  Keyboard.send_now();
}
//
// Function to set a pin to high impedance (acts like open drain output that is floating)
void go_z(int pin)
{
  pinMode(pin, INPUT);
  digitalWrite(pin, HIGH);
}
//
// Function to set a pin as an input with a pullup
void go_pu(int pin)
{
  pinMode(pin, INPUT_PULLUP);
  digitalWrite(pin, HIGH);
}
//
// Function to send a pin to a logic low
void go_0(int pin)
{
  pinMode(pin, OUTPUT);
  digitalWrite(pin, LOW);
}
//
// Function to send a pin to a logic high
void go_1(int pin)
{
  pinMode(pin, OUTPUT);
  digitalWrite(pin, HIGH);
}
// **********Functions for Video Control******************
//
// Function to pulse the Menu pin low
void pulse_menu()
{
  go_0(VIDEO_MENU); //Drive Menu pin low
  delay(200);
  go_z(VIDEO_MENU); //let Menu pin go high
  delay(300);
}
// Function to pulse the Right pin low
void pulse_right()
{
  go_0(VIDEO_RIGHT); //Drive Right pin low
  delay(200);
  go_z(VIDEO_RIGHT);  //Let Right pin go high
  delay(300);
}
//
// *****************Functions for Touchpad***************************
//
// Function to send the touchpad a byte of data (command)
//
void tp_write(char send_data)  
{
  unsigned int timeout = 200; // breakout of loop if over this value in msec
  elapsedMillis watchdog; // zero the watchdog timer clock
  char odd_parity = 0; // clear parity bit count
// Enable the bus by floating the clock and data
  go_pu(TP_CLK); //
  go_pu(TP_DATA); //
  delayMicroseconds(250); // wait before requesting the bus
  go_0(TP_CLK); //   Send the Clock line low to request to transmit data
  delayMicroseconds(100); // wait for 100 microseconds per bus spec
  go_0(TP_DATA); //  Send the Data line low (the start bit)
  delayMicroseconds(1); //
  go_pu(TP_CLK); //   Release the Clock line so it is pulled high
  delayMicroseconds(1); // give some time to let the clock line go high
  while (digitalRead(TP_CLK) == HIGH) { // loop until the clock goes low
    if (watchdog >= timeout) { //check for infinite loop
      break; // break out of infinite loop
    }
  }
// send the 8 bits of send_data 
  for (int j=0; j<8; j++) {
    if (send_data & 1) {  //check if lsb is set
      go_pu(TP_DATA); // send a 1 to TP
      odd_parity = odd_parity + 1; // keep running total of 1's sent
    }
    else {
      go_0(TP_DATA); // send a 0 to TP
    }
    delayMicroseconds(1); // delay to let the clock settle out
    while (digitalRead(TP_CLK) == LOW) { // loop until the clock goes high
      if (watchdog >= timeout) { //check for infinite loop
        break; // break out of infinite loop
      }
    }
    delayMicroseconds(1); // delay to let the clock settle out
    while (digitalRead(TP_CLK) == HIGH) { // loop until the clock goes low
      if (watchdog >= timeout) { //check for infinite loop
        break; // break out of infinite loop
      }
    }  
    send_data = send_data >> 1; // shift data right by 1 to prepare for next loop
  }
// send the parity bit
  if (odd_parity & 1) {  //check if lsb of parity is set
    go_0(TP_DATA); // already odd so send a 0 to TP
  }
  else {
    go_pu(TP_DATA); // send a 1 to TP to make parity odd
  }   
  delayMicroseconds(1); // delay to let the clock settle out
  while (digitalRead(TP_CLK) == LOW) { // loop until the clock goes high
    if (watchdog >= timeout) { //check for infinite loop
      break; // break out of infinite loop
    }
  }
  delayMicroseconds(1); // delay to let the clock settle out
  while (digitalRead(TP_CLK) == HIGH) { // loop until the clock goes low
    if (watchdog >= timeout) { //check for infinite loop
      break; // break out of infinite loop
    }
  }
  go_pu(TP_DATA); //  Release the Data line so it goes high as the stop bit
  delayMicroseconds(80); // testing shows delay at least 40us 
  while (digitalRead(TP_CLK) == HIGH) { // loop until the clock goes low
    if (watchdog >= timeout) { //check for infinite loop
      break; // break out of infinite loop
    }
  }
  delayMicroseconds(1); // wait to let the data settle
  if (digitalRead(TP_DATA)) { // Ack bit s/b low if good transfer
  }
  while ((digitalRead(TP_CLK) == LOW) || (digitalRead(TP_DATA) == LOW)) { // loop if clock or data are low
    if (watchdog >= timeout) { //check for infinite loop
      break; // break out of infinite loop
    }
  }
// Inhibit the bus so the tp only talks when we're listening
  go_0(TP_CLK);
}
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
void loop() {   
// Scan keyboard matrix with an outer loop that drives each row low and an inner loop that reads every column (with pull ups).
// The routine looks at each key's present state (by reading the column input pin) and also the previous state from the last scan
// that was 30msec ago. The status of a key that was just pressed or just released is sent over USB and the state is saved in the old_key matrix. 
// The keyboard keys will read as logic low if they are pressed (negative logic).
// The old_key matrix also uses negative logic (low=pressed). 
//
  for (int x = 0; x < rows_max; x++) {   // loop thru the rows
    go_0(Row_IO[x]); // Activate Row (send it low)
    delayMicroseconds(10); // give the row time to go low and settle out
    for (int y = 0; y < cols_max; y++) {   // loop thru the columns
// **********Modifier keys including the Fn special case
      if (modifier[x][y] != 0) {  // check if modifier key exists at this location in the array (a non-zero value)
        if (!digitalRead(Col_IO[y]) && (old_key[x][y])) {  // Read column to see if key is low (pressed) and was previously not pressed
          if (modifier[x][y] != MODIFIERKEY_FN) {   // Exclude Fn modifier key  
            load_mod(modifier[x][y]); // function reads which modifier key is pressed and loads it into the appropriate mod_... variable   
            send_mod(); // function sends the state of all modifier keys over usb including the one that just got pressed
            old_key[x][y] = LOW; // Save state of key as "pressed"
          }
          else {   
            Fn_pressed = LOW; // Fn status variable is active low
            old_key[x][y] = LOW; // old_key state is "pressed" (active low)
          }
        }
        else if (digitalRead(Col_IO[y]) && (!old_key[x][y])) {  //check if key is not pressed and was previously pressed
          if (modifier[x][y] != MODIFIERKEY_FN) { // Exclude Fn modifier key 
            clear_mod(modifier[x][y]); // function reads which modifier key was released and loads 0 into the appropriate mod_... variable
            send_mod(); // function sends all mod's over usb including the one that just released
            old_key[x][y] = HIGH; // Save state of key as "not pressed"
          }
          else {
            Fn_pressed = HIGH; // Fn is no longer active
            old_key[x][y] = HIGH; // old_key state is "not pressed" 
          }
        }
      } 
// ***********end of modifier section
//
// ***********Normal keys and media keys in this section
      else if ((normal[x][y] != 0) || (media[x][y] != 0)) {  // check if normal or media key exists at this location in the array
        if (!digitalRead(Col_IO[y]) && (old_key[x][y]) && (!slots_full)) { // check if key is pressed and was not previously pressed and slots not full
          old_key[x][y] = LOW; // Save state of key as "pressed"
          if (Fn_pressed) {  // Fn_pressed is active low so it is not pressed and normal key needs to be sent
            load_slot(normal[x][y]); //update first available slot with normal key name
            send_normals(); // send all slots over USB including the key that just got pressed
          }
          else if (media[x][y] != 0) { // Fn is pressed so send media if a key exists in the matrix
            Keyboard.press(media[x][y]); // media key is sent using keyboard press function per PJRC    
            delay(5); // delay 5 milliseconds before releasing to make sure it gets sent over USB
            Keyboard.release(media[x][y]); // send media key release
          }
          else if (normal[x][y] == KEY_F8) { // Fn and F8 are both pressed 
          // move down into the video source selection screen
            pulse_menu();
            pulse_right();
            pulse_menu();
            pulse_right();
            pulse_right();
            pulse_right();
            pulse_right();
            pulse_menu();
            delay(1000);
          // pulse Right every second to cycle thru the video sources
            while (!digitalRead(Col_IO[y])) {  // loop until F8 key is released
              pulse_right();
              delay(1000);  
            }
            pulse_menu(); // select the video source currently highlighted
          }
        }          
        else if (digitalRead(Col_IO[y]) && (!old_key[x][y])) { //check if key is not pressed, but was previously pressed 
          old_key[x][y] = HIGH; // Save state of key as "not pressed"
          if (Fn_pressed) {  // Fn is not pressed
            clear_slot(normal[x][y]); //clear the slot that contains the normal key name
            send_normals(); // send all slots over USB including the key that was just released 
          }
        }
      } 
// **************end of normal and media key section 
//
    }
    go_z(Row_IO[x]); // De-activate Row (send it to hi-z)
  }
//
// Turn on or off the LEDs for Num Lock, Caps Lock, and Scroll Lock based on bit 0, 1, and 2 from the keyboard_leds 
// variable controlled by the USB host computer
//
  if (keyboard_leds & 1) {  // mask off all bits but D0 and test if set
    go_0(NUM_LED); // turn on the Num Lock LED
  }
  else {
    go_1(NUM_LED); // turn off the Num Lock LED
  }
//
//
  if (keyboard_leds & 1<<1) {  // mask off all bits but D1 and test if set
    go_0(CAPS_LED); // turn on the Caps Lock LED
  }
  else {
    go_1(CAPS_LED); // turn off the Caps Lock LED
  }
//
// **********Keyboard scan complete
//
// ***********Touchpad Section
//
  if (touchpad_error == LOW) { // check if touchpad is present
//
// poll the touchpad for new movement data
    over_flow = 0; // assume no overflow until status is received 
    tp_write(0xeb);  // request data
    if (tp_read() != 0xfa) { // verify correct ack byte
      // bad ack - pass to future error handler
    }
    mstat = tp_read(); // save into status variable
    mx = tp_read(); // save into x variable
    my = tp_read(); // save into y variable
    if (((0x80 & mstat) == 0x80) || ((0x40 & mstat) == 0x40))  {   // x or y overflow bits set?
      over_flow = 1; // set the overflow flag
    }   
// change the x data from 9 bit to 8 bit 2's complement
    mx = mx & 0x7f; // mask off 8th bit
    if ((0x10 & mstat) == 0x10) {   // move the sign into 
      mx = 0x80 | mx;              // the 8th bit position
    } 
// change the y data from 9 bit to 8 bit 2's complement and then take the 2's complement 
// because y movement on ps/2 format is opposite of touchpad.move function
    my = my & 0x7f; // mask off 8th bit
    if ((0x20 & mstat) == 0x20) {   // move the sign into 
      my = 0x80 | my;              // the 8th bit position
    } 
    my = (~my + 0x01); // change the sign of y data by taking the 2's complement (invert and add 1)
// zero out mx and my if over_flow is set
    if (over_flow) { 
      mx = 0x00;       // data is garbage so zero it out
      my = 0x00;
    } 
// send the x and y data back via usb if either one is non-zero
    if ((mx != 0x00) || (my != 0x00)) {
      Mouse.move(mx,my);
    }
//
// send the touchpad left and right button status over usb if no error
    if ((0x01 & mstat) == 0x01) {   // if left button set 
      left_button = 1;   
    }
    else {   // clear left button
      left_button = 0;   
    }
    if ((0x02 & mstat) == 0x02) {   // if right button set 
      right_button = 1;   
    } 
    else {   // clear right button
      right_button = 0;  
    }
// Determine if the left or right touchpad buttons have changed since last polling cycle
    button_change = (left_button ^ old_left_button) | (right_button ^ old_right_button);
// Don't send button status if there's no change since last time. 
    if (button_change){
      Mouse.set_buttons(left_button, 0, right_button); // send button status
    }
    old_left_button = left_button; // remember new button status for next polling cycle
    old_right_button = right_button;
  }
//
// End of touchpad routine
//
// Check if on/off switch is being held down to turn off laptop
  if (!power_switch()) { // is it pushed?
    off_count++; // increment counter
    if (off_count >= 80) { // check if counter has reached 5 seconds
      go_1(TURN_OFF); // 5 seconds so disable the buck regulators
    }
  }
  else {
    off_count = 0; // zero the counter
  }
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

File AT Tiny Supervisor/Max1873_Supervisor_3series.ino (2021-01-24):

/* Copyright 2021 Frank Adams
   Licensed under the Apache License, Version 2.0 (the "License");
   you may not use this file except in compliance with the License.
   You may obtain a copy of the License at
       http://www.apache.org/licenses/LICENSE-2.0
   Unless required by applicable law or agreed to in writing, software
   distributed under the License is distributed on an "AS IS" BASIS,
   WITHOUT WARRANTIES OR CONDITIONS OF ANY KIND, either express or implied.
   See the License for the specific language governing permissions and
   limitations under the License.
*/
// This ATTiny85 program controls the enable pin on the Max1873 so it will safely charge the Li+ laptop battery in a 3 series pack.
// Assumptions: 
//    a. Maximum battery charge current is set at 1 amp.
//    b. Battery Pack has 3 series cells, each cell fully charged at 4.2 volts, giving a pack voltage of 12.6 volts.
//    c. NTC Thermistor resistance in ohms is 13.6K @ 18C, 9.3K @ 27C, 5.3K @ 41C, 3.2K @ 59C
//    d. Charge current, battery voltage, and Temperature inputs to the ATTiny use the resistor divider values on the schematic. 
// Program Features:
// 1. The ATTiny keeps track of how long charging has been going on and shuts down the Max1873 after a defined maximum time. 
// 2. The Pi uses a GPIO pin to send a 3.3 volt logic signal to the ATTiny to turn off charging. 
//    This should be done if the Pi detects (over the SM Bus) that the battery temperature or voltage has gone too high.
// 3. The ATTiny ADC reads the battery temperature sensor (10K NTC thermistor) at startup and then while charging to see 
//    if the temperature rises too much and the Max1873 needs to stop charging. 
// 4. The ATTiny ADC reads the battery voltage prior to enabling the charger to see if the battery is ready for a normal charge. 
//    If the voltage is too low, the routine will pulse the charger enable signal to slowly bring the battery voltage up. 
//    The pulse duration will increase as the battery voltage rises.
// 5. The ATTiny ADC reads the charge current from the Iout pin of the Max1873 to see when it has reached trickle
//    charge levels and then shuts down charging. 
//
// Some Dell batteries will need SMBus communication from the Pi before they will accept charge current. 
// If the ATTiny reads a charge current at or near zero, (meaning the battery is not accepting a charge), 
// the Max1873 is kept enabled so that when the Pi sends the appropriate commands over the SM Bus, the battery will begin charging.
//   
// The ATTiny is powered from the low voltage (5.4V) regulator in the Max1873 which only operates when the 19.5VDC wall supply is  
// plugged in. This Max1873 regulator can only source 3ma and it meaasures 2.5ma when the ATTiny is running at 1MHz.  
// Any higher clock frequency will overload the regulator. It will also overload the regulator if the analog input voltages
// are between 1.5 and 2.5 volts. To avoid this, the internal 1.1 volt ADC reference is used and all analog input 
// voltages are scaled down to 1.1 volts max. 

// Release History
// July 1, 2020  Original Release

// ATTiny Logic Pins
#define pi_turnoff 0 // Pin 5 PB0 is an input. 1=turnoff. PCB has external pull down resistor
#define max_en 1 // Pin 6 PB1 drives BS170 NFET that turns Max1873 on and off. 0=On, 1=Off
// ATTiny Analog Pins
#define Vbat A1 // Pin 7 ADC1 receives divided down battery pack voltage
#define bat_temp A2 // Pin 3 ADC2 receives divided down battery temperature voltage
#define iout A3 // Pin 2 ADC3 receives divided down Max1873 Iout voltage
// Battery charging values
#define precharge 492 // this is a battery voltage of 9 volts. Pulse charge until voltage is above this level.
#define trickle 233 // Trickle charge trip level that turns off the charger. 233=250ma charge current
#define no_charge 11 // Near zero "no-charge" level equates to 12ma
#define temp_limit 150 // 150 is roughly a 10 degree temperature increase
#define max_minutes 300 // maximum charging time in minutes

// Globals
int pulse_on = 100; // "On" time in msec for precharge. This is adjusted based on the battery voltage
int pulse_off = 1900; // "Off" time in msec for precharge. This is adjusted to give a total cycle time of 2 seconds
int charge_level; // holds ADC average value from Iout pin of Max1873.  
int old_charge_level = 750; // holds ADC value from the previous loop
int temperature; // holds adc average value from 10K NTC battery temperature thermistor 
int temperature_start; // holds adc average value from battery temperature thermistor at power up
int battery_voltage; // holds adc average value of battery pack voltage 
int minute_count = 0; // Minute counter
int loop_count = 0; // Loop counter

// Function reads the selected ADC channel multiple times with the specified wait time between reads
int read_adc(int wait, int adc_chan) 
{ 
  int val_1 = analogRead(adc_chan); // first read after selecting the ADC channel is suspect so throw it away
  delay(wait); // wait before reading again
  val_1 = analogRead(adc_chan); // save this as the more accurate first read
  delay(wait); // wait before reading again
  int val_2 = analogRead(adc_chan);  // second read
  delay(wait); // wait before reading again
  int val_3 = analogRead(adc_chan);  // third read
  delay(wait); // wait before reading again
  int val_4 = analogRead(adc_chan);  // fourth read
  return ((val_1 + val_2 + val_3 + val_4)/4); // return average ranging from 0 to 1023 for 0 to 1.1 volts.   
}
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

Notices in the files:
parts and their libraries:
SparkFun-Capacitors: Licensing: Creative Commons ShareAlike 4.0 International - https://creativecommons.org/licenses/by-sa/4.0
